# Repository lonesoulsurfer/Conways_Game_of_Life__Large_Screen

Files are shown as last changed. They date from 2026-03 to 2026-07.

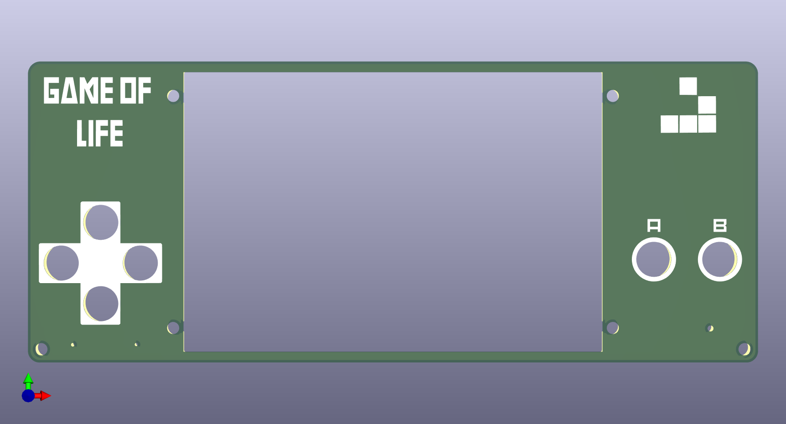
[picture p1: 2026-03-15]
Front Panel - Kicad 3D.png

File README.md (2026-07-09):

EKFB7789

**YouTube:** https://studio.youtube.com/video/bC17AgROvXw/edit

**Instructable:** https://www.instructables.com/Conways-Game-of-Life-XL-Screen-Raspberry-Pi-Projec/

### ▶ [Try the Web Simulator](https://htmlpreview.github.io/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) — no hardware required, runs in your browser

---

## Contents

- [Hardware & Setup](#hardware--setup)
- [Web Simulator](#web-simulator)
- [Main Menu](#main-menu)
- [Standard Controls](#standard-controls-conway--alt-games--rule-explorer)
- [Conway's Life Modes](#conways-life-modes)
- [Alternative Cellular Automata (Alt Games)](#alternative-cellular-automata-alt-games)
- [Lenia Sandbox](#lenia-sandbox)
- [Tools Menu](#tools-menu)
- [Arcade Games](#arcade-games)

---

## Hardware & Setup

The device runs on a Raspberry Pi Pico / RP2040 connected to a 3.5" ST7796S/ST7796U TFT display (480×320 pixels) via SPI. Six buttons handle all navigation and gameplay: Up, Down, Left, Right, SET (A), and B. A buzzer on GPIO 26 provides sound effects and music. Display brightness is PWM-controlled, and all settings (sound, volume, brightness) are saved to EEPROM so they persist between power cycles.

## Web Simulator

Don't have the hardware? [**Game_of_Life_Simulation.html**](Game_of_Life_Simulation.html) is a single-file, browser-based recreation of the firmware that runs on any modern desktop browser — [click here to launch it directly](https://htmlpreview.github.io/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), or download the file and open it locally.

It's a faithful port of the firmware's menu logic and simulation rules, built directly from this repo's source — not a from-scratch reimplementation. It covers:

- The full Conway's Life menu shell: Presets, Random, Symmetric, Custom, and Rule Explorer (including the Custom Rule bit editor)
- All seven Alt Games automata: Brian's Brain, Day & Night, Seeds, Cyclic CA, Wireworld, Langton's Ant, and Wolfram 1D
- The Lenia Sandbox, with its own live parameter panel and control scheme
- The Tools menu (Grid Lines, Population Counter, Trail Mode, Colour Mode, Toroidal World)

On-screen buttons mirror the physical Up/Down/Left/Right/A/B layout, and the same controls also work from a keyboard (arrow keys, A/Enter/Space, B) — including two-button combos like Up+Down for colour mode.

**Not included:** Arcade Games (Star Wars, Breakout Beyond, Gyruss) and hardware-only features like sound and screen brightness, which don't have a meaningful browser equivalent.

## Main Menu

On startup the device boots directly into the main scrolling menu with eight sections:

| # | Section | Description |
|---|---|---|
| 1 | Presets | Hand-crafted Conway's Life patterns |
| 2 | Random | Randomised Conway's Life |
| 3 | Symmetric | Procedurally generated symmetric patterns |
| 4 | Custom | Draw your own pattern |
| 5 | Rule Explorer | Define custom birth/survival rules |
| 6 | Alt Games | Alternative cellular automata (including Lenia Sandbox) |
| 7 | Tools | Display and simulation settings |
| 8 | Arcade | Three built-in arcade games |

Navigate with Up/Down, select with SET, go back with B.

## Standard Controls (Conway / Alt Games / Rule Explorer)

These controls apply to Conway's Life modes, Rule Explorer, and every Alt Games automaton except Lenia Sandbox, which has its own control scheme. See the [Lenia Sandbox](#lenia-sandbox) section.

| Button | Action |
|---|---|
| Up | Increase simulation speed |
| Down | Decrease simulation speed |
| Left | Cycle cell size (Small 3px, Normal 4px, Large 8px) |
| Right | Reset / regenerate the current pattern |
| Up + Down | Toggle colour mode |
| SET (hold) | Start simulation from edit mode |
| SET (hold, running) | Return to edit mode (Custom / Seeds / Brian's Brain only) |
| B (short press) | Return to menu |
| B (hold ~1 second) | Show/hide rules and information panel |

## Conway's Life Modes

### Presets (13 patterns)

Press SET once to open a preset, then A to start the simulation. While paused you can press Left to change cell size (the pattern rescales and redraws) or Right to reset it back to its starting state.

| # | Pattern | Notes |
|---|---|---|
| 1 | Coe Ship | Puffer-type spaceship that leaves debris trails |
| 2 | Gosper Gun | The first glider gun ever discovered, period 30 |
| 3 | Diamond | Symmetric expanding diamond pattern |
| 4 | Achim p144 | Rare period-144 oscillator |
| 5 | 56P6H1V0 | High-period spaceship |
| 6 | LWSS Convoy | Three Lightweight Spaceships in formation |
| 7 | MWSS | Middleweight Spaceship, 8 cells, speed c/2 |
| 8 | Pulsar | Period-3 oscillator with 4-fold symmetry, 48 cells |
| 9 | Pentadecathlon | 15-cell oscillator made from a modified 10-cell row |
| 10 | R-Pentomino | 5-cell seed that runs for 1,103 generations |
| 11 | Acorn | 7-cell methuselah running 5,206 generations |
| 12 | Simkin Gun | Smallest known glider gun, 36 cells, period 120 |
| 13 | Queen Bee | Period-30 oscillator, the first of its kind ever found |

### Random

Fills the board with random live cells at approximately 30% density. Immediately starts running. Press Right to re-randomise.

### Symmetric

Generates a random pattern with one of three symmetry types (vertical, horizontal, or rotational) in small, medium, or large sizes. Good for producing structured chaos.

### Custom

Puts the board into edit mode with a blinking red crosshair cursor. Move the cursor with Up/Down/Left/Right. Press SET to toggle a cell on or off. When happy with your pattern, hold SET for about a second to start the simulation. Hold SET again to return to edit mode. Press B to go back to the menu.

### Rule Explorer

Define your own cellular automaton by setting custom Birth (B) and Survival (S) rules, the same notation used by Life (B3/S23). Choose from 12 built-in rule presets or enter your own bit-by-bit. The simulation runs with your rules applied to a random starting board.

**Included preset rules:** High Life, 34 Life, Diamoeba, Replicator, Long Life, Maze, Coral, 2x2, Dry Life, Amoeba, Coagulate, Gnarl

## Alternative Cellular Automata (Alt Games)

**Brian's Brain.** A three-state automaton (On, Dying, Off) producing a constantly moving stream of light-speed "signals." Choose from small, medium, large, or random seedings, or draw a custom starting pattern.

**Day & Night** (B3678/S34678). A symmetric ruleset where dead and live regions are interchangeable. Dense regions survive and grow in a way that mirrors the original, creating organic, blob-like patterns.

**Seeds** (B2/S). Every live cell dies every generation but any dead cell with exactly two live neighbours is born. Creates explosive, constantly moving patterns that never stabilise.

**Cyclic CA.** A multi-state automaton where cells cycle through states 0→1→2→…→N→0. Cells advance only when they have a neighbour in the next state. Produces rotating spiral waves. Choose small, medium, or large seedings.

**Wireworld.** A four-state automaton (Empty, Wire, Electron Head, Electron Tail) that models digital logic circuits. Electrons travel along wires, interact at junctions, and can form AND gates and clocks. The built-in demo includes a working circuit layout.

**Langton's Ant.** A single ant on a grid follows two rules: turn right on a white cell and flip it black, turn left on a black cell and flip it white. After roughly 10,000 chaotic steps it spontaneously builds a repeating diagonal "highway." Toggle age-colour mode with Up+Down to see a heat map of how often each cell has been visited.

**Wolfram 1D Automata.** One-dimensional elementary cellular automata: a single row of cells evolves downward according to one of 255 possible rules. Each rule produces a unique pattern, from pure chaos (Rule 30) to the Sierpinski triangle (Rule 90) to a Turing-complete system (Rule 110). Seven named presets are provided, or you can enter any rule number directly.

**Lenia Sandbox.** A continuous cellular automaton with its own control scheme, described below.

## Lenia Sandbox

Unlike every automaton above, Lenia isn't discrete. Cells hold a value from 0-255 instead of a simple on/off state, and each step blends that value with a weighted neighbourhood (the kernel) instead of applying binary birth/survival rules. The result is smooth, organic life forms that grow and drift.

The play area occupies the right two-thirds of the screen, with a live parameter panel on the left third.

**Parameters** (adjust with Up/Down to select, Left/Right to change value):

| Parameter | Meaning |
|---|---|
| Mu | Growth centre: the neighbourhood value that produces the strongest growth |
| Sigma | Growth width: how forgiving that target value is |
| Radius | How far each cell looks at its neighbours |
| Speed | How much each step nudges the field (time step / dt) |

**Controls:**

| Button | Action |
|---|---|
| Up / Down | Select a parameter row |
| Left / Right | Adjust the selected parameter |
| SET (A) | Reseed the board with fresh random blobs |
| Up + Down | Toggle colour scheme (blue/cyan/white or fire) |
| B (short tap) | Return to the Alt Games menu |
| B (hold ~1 second) | Show/hide the rules and parameter info panel |
| SET + B (hold ~1 second) | Full reset: parameters back to defaults, fresh seed |

Honours the shared Toroidal World setting from the Tools menu (wrap edges on/off) and the Auto-Cycle screensaver tool (periodically reseeds on its own, same as the other automata).

## Tools Menu

**Grid Lines.** Overlays a faint grid matching the current cell size.

**Population Counter.** Shows live cell count and generation number during simulation.

**Trail Mode.** Dying cells leave a soft 20-step fade trail rather than disappearing instantly.

**Colour Mode.** Age-based colouring; young cells are one colour, older cells shift through the spectrum.

**Toroidal World.** When on, edges wrap around so the board is a torus. When off, edges are hard boundaries.

**Brightness.** Four levels: 25%, 50%, 75%, 100%.

**Auto-Cycle / Screensaver.** Automatically switches to a random game mode or Wolfram rule every 300 generations. Useful as a display piece.

**Sound settings.** Enabled/disabled, three volume levels. Also accessible here and saved to EEPROM.

## Arcade Games

Accessed from main menu item 8. Three games are available. In all three, press A + B together at any time to exit directly back to the main menu.

### Star Wars

A first-person Star Wars game inspired by the 80's arcade game. Progress through multiple stages: Womp Rat Training, Space Battle, Death Star Approach, Surface Run, and the Exhaust Port shot. Features full Star Wars music (Main Theme, Binary Sunset, Imperial March, Victory Fanfare), sound effects, TIE fighters, laser cannons, proton torpedoes, and a dramatic finale sequence. Press B on the title screen to exit.

| Button | Action |
|---|---|
| Up/Down/Left/Right | Move crosshair / pilot ship |
| SET | Fire |
| A + B | Exit to main menu |
| Up + Down (title screen) | Enter games menu to play any of the games or watch the cinematic shorts |

### Breakout Beyond

A feature-rich Breakout variant with a neon aesthetic. The paddle sits at the bottom, bricks at the top. Features include combo multipliers, spin physics, multiball, shield power-ups, bomb bricks, and hard bricks across 20 levels.

| Button | Action |
|---|---|
| Left/Right | Move paddle |
| B | Speed boost |
| SET | Launch ball / pause |
| A + B (hold) | Exit to main menu |

### Gyruss

A circular shoot-em-up inspired by the 1983 Konami arcade classic. Your ship orbits around the edge of the screen shooting inward at waves of enemies that fly in formation patterns.

| Button | Action |
|---|---|
| Left/Right | Rotate ship around the ring |
| SET or B | Fire |
| Up (hold) | Smart bomb |
| A + B (hold) | Exit to main menu |

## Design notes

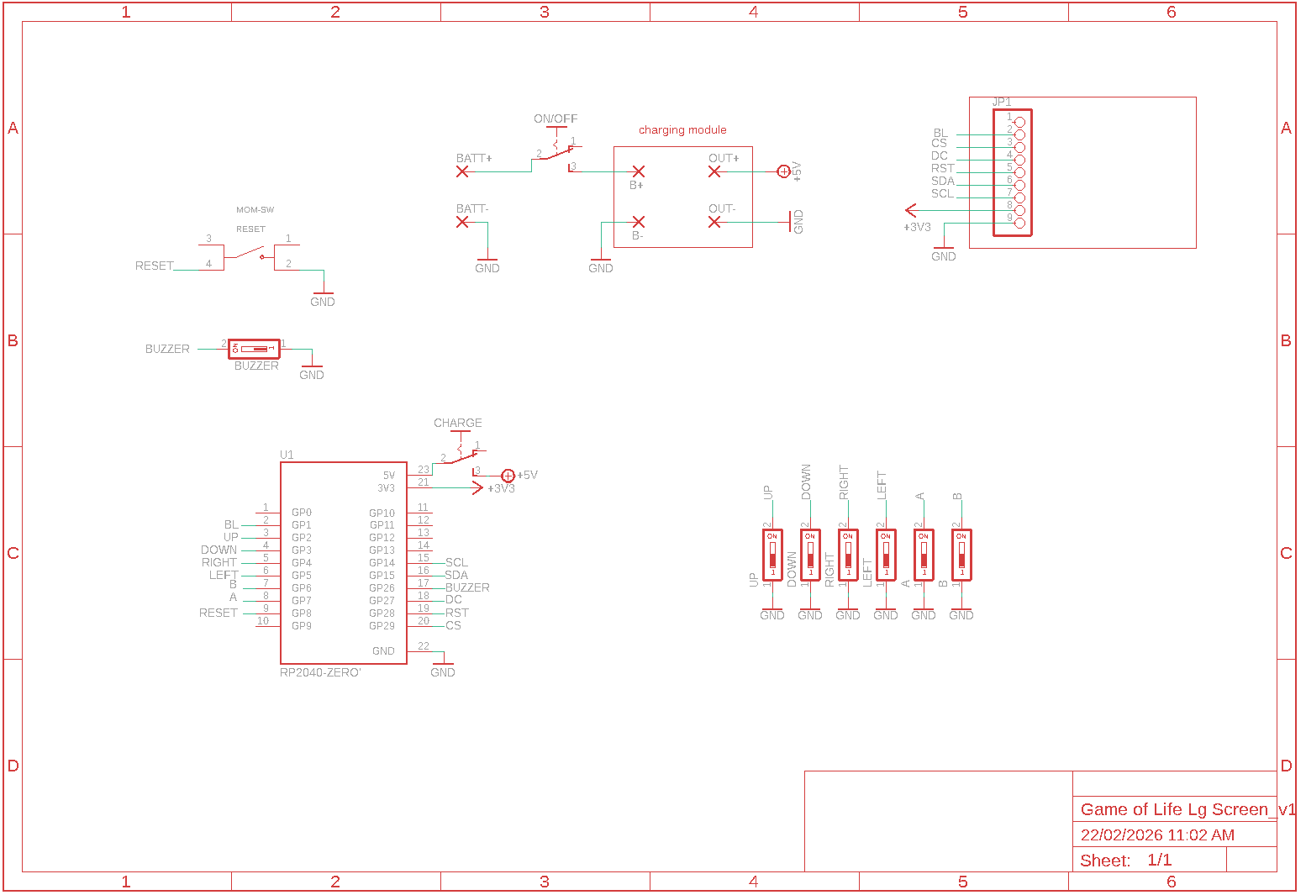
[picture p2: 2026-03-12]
Schematic.png

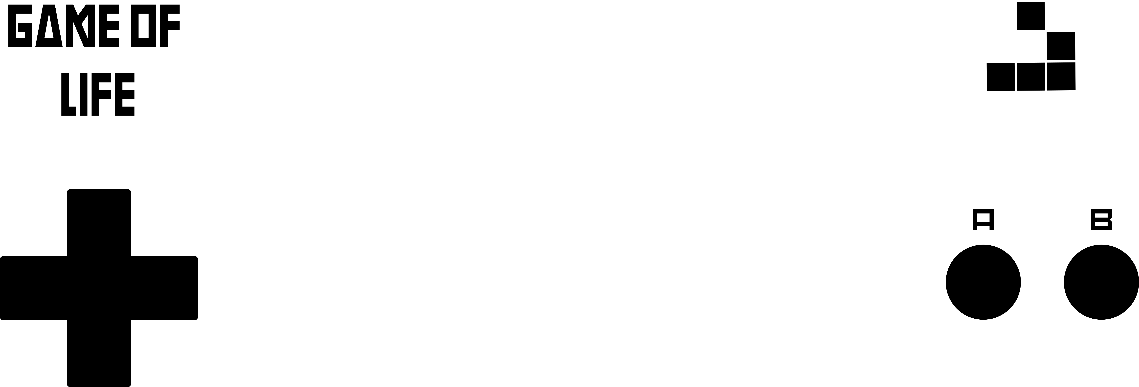
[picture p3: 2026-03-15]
Panel Design/Front Panel/GOL - Lg Sceen - Front Panel.png

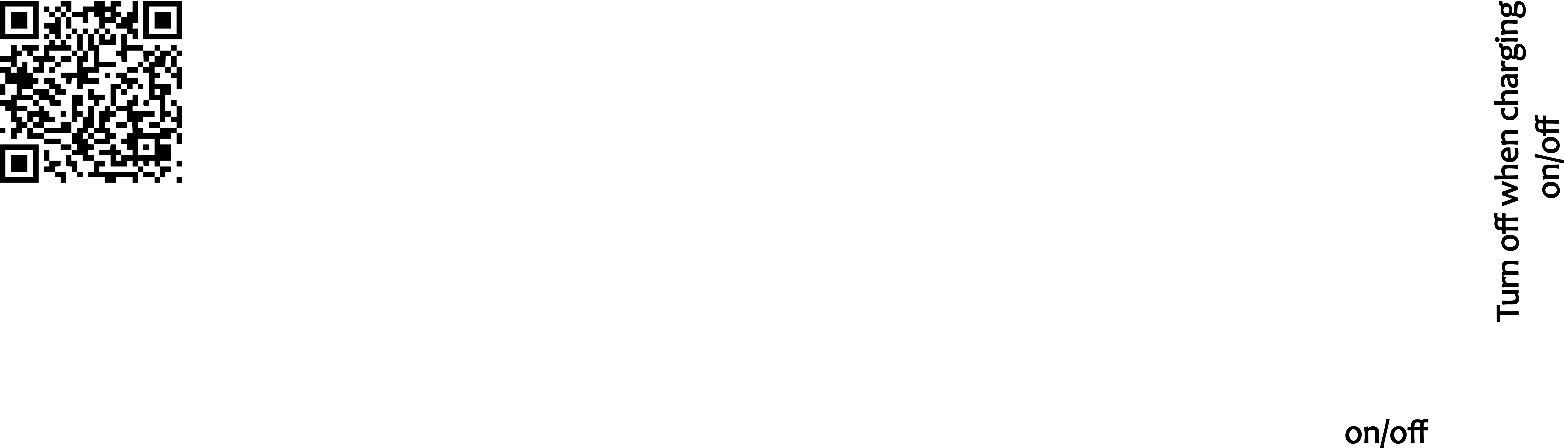
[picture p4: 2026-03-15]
Panel Design/Back Panel/Game of Life Lg Screen - Back Panel.png

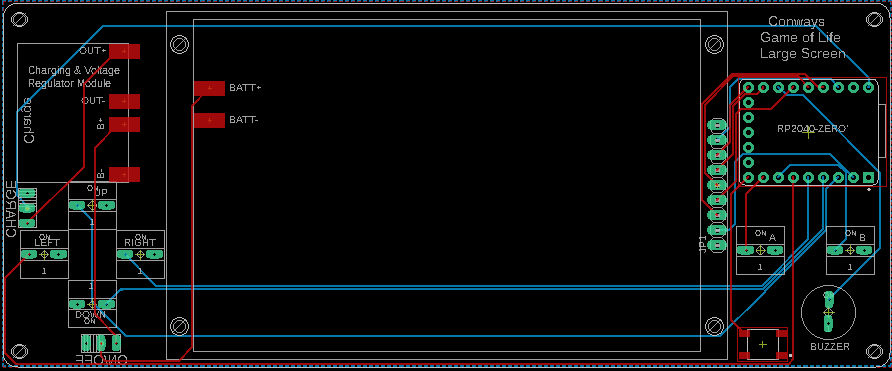
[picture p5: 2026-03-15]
Board.png

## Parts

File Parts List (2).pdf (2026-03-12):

Part | Type | Part Number | Qty | Link | Image
Switches | Momentary Switches Slide Switch Tactile Tact Push Button -4 pin | SKRCADD010 MSK-12D19 | 6 2 1 | Link (https://www.aliexpress.com/item/4000550502648.html) Link (https://www.aliexpress.com/item/32828124825.html?srcSns=sns_More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) Link (https://www.aliexpress.com/item/1005006195658674.html?curPageLogUid=UlWXQG9WxOqp)

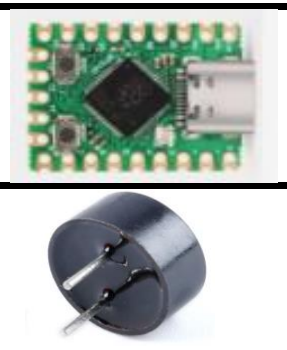
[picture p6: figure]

Raspberry Pi Pico Zero | | | 1 | Link (https://www.aliexpress.com/w/wholesale-Raspberry-PI-Pico-Mini-RP2040%2525252dZERO-Microcontroller.html)
Buzzer | Passive (9mm X 3.2mm) SMD | | 1 | Link (https://www.aliexpress.com/w/wholesale-9042-buzzer.html?spm=a2g0o.detail.search.0)
TFT Display | 3.5 inch OLED LCD Drive IC 320 X 480 | ST7796S/ ST7796U | 1 | Link (https://www.aliexpress.com/w/wholesale-TFT-Display-2.0-inch-OLED-LCD-Drive-IC-ST7789V-240.html)

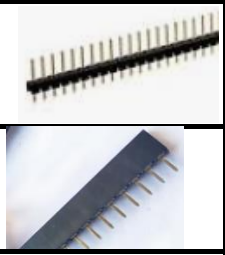
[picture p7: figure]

Header Pins | Male - SMT 2.54mm | | (2 X 9) | Link (https://www.aliexpress.com/w/wholesale-pin-headers-single-row.html?spm=a2g0o.productlist.search.0)
| Female - Lo profile | | (2 X 9) | Link (https://www.aliexpress.com/item/1005004122312694.html?curPageLogUid=kHqHT0cRd9pW)
Nylon Hex Spacers | M2 - assorted | | 1 | Link (https://www.aliexpress.com/item/1005007123661699.html)
Hex Socket Screw Kit | Ms - Assorted | DIN912 | 1 | Link (https://www.aliexpress.com/item/1005007273134914.html?curPageLogUid=XMboOUAJHQU8)
Battery | Lipo - (Mobile) | EB-BJ700BBC EB-BJ700CBE | 1 | Link (https://www.aliexpress.com/item/1005007768846321.html?curPageLogUid=MjolbnGyNA4R)
Charging & Voltage Module | 3.7V To 9V 5V 2A DC-DC Step Up Boost Modul | | 1 | Link (https://www.aliexpress.com/item/1005005656423941.html?srcSns=sns_More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)

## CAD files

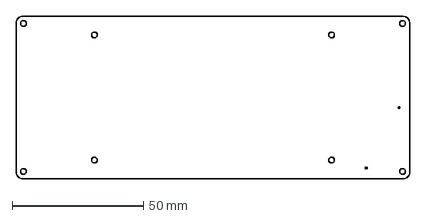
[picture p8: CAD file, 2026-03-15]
Panel Design/Back Panel/GOL Lg Screen - Back Panel - Fusion.dxf
150.1 x 61.9 mm

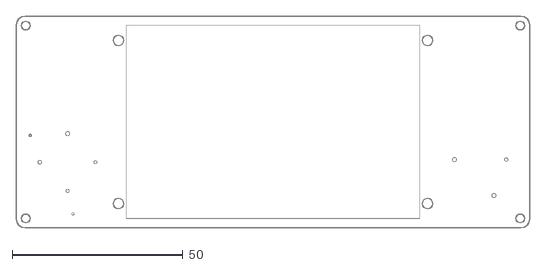
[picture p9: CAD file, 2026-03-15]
Panel Design/Front Panel/Game of Life Lg Screen PCB.dxf
150.1 x 61.9

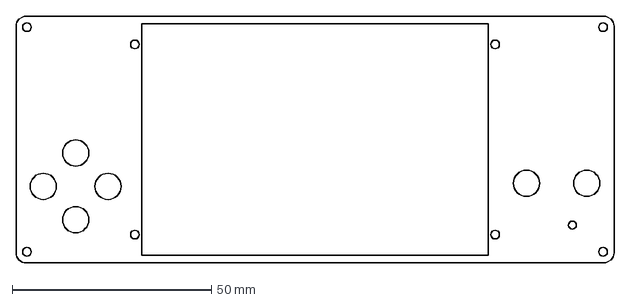
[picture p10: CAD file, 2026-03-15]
Panel Design/Front Panel/Game of Life Lg Screen Fusion.dxf
150.1 x 61.9 mm

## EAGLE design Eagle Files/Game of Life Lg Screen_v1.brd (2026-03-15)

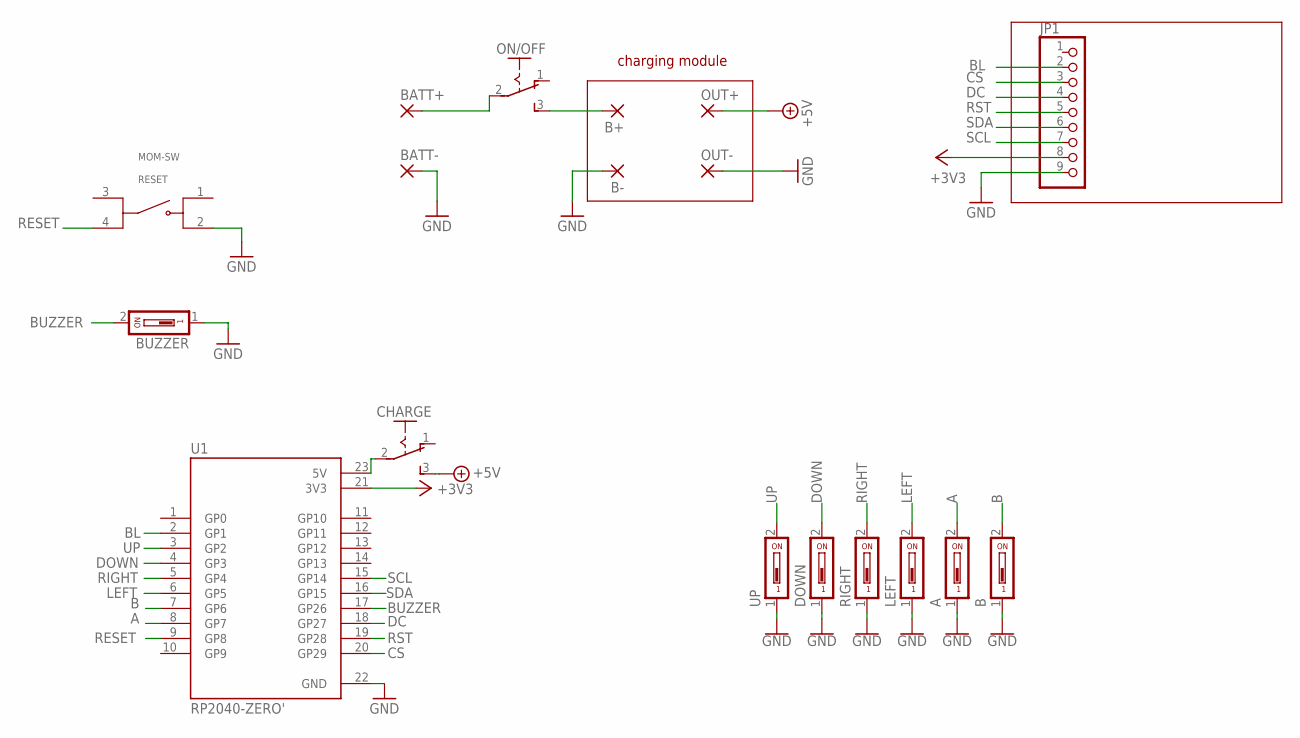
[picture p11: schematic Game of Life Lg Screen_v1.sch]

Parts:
A: DS01; DS-01
B: DS01; DS-01
B+: SMD5; SMD2,54-5,08
B-: SMD5; SMD2,54-5,08
BATT+: SMD5; SMD2,54-5,08
BATT-: SMD5; SMD2,54-5,08
BUZZER: DS01; DS-01
CHARGE: M251
DOWN: DS01; DS-01
JP1: PINHD-1X9; 1X09
LEFT: DS01; DS-01
ON/OFF: M251
OUT+: SMD5; SMD2,54-5,08
OUT-: SMD5; SMD2,54-5,08
RESET: MOM-SW; SW_TS18-5-25-SL-260-SMT-TR
RIGHT: DS01; DS-01
U1: RP2040-ZERO'; MODULE_RP2040-ZERO
UP: DS01; DS-01

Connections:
+3V3: JP1.8, U1.21 (3V3)
+5V: CHARGE.3 (S), OUT+.1
A: A.2, U1.8 (GP7)
B: B.2, U1.7 (GP6)
BL: JP1.2, U1.2 (GP1)
BUZZER: BUZZER.2, U1.17 (GP26)
CS: JP1.3, U1.20 (GP29)
DC: JP1.4, U1.18 (GP27)
DOWN: DOWN.2, U1.4 (GP3)
GND: A.1, B.1, B-.1, BATT-.1, BUZZER.1, DOWN.1, JP1.9, LEFT.1, OUT-.1, RESET.2, RIGHT.1, U1.22 (GND), UP.1
LEFT: LEFT.2, U1.6 (GP5)
unnamed: B+.1, ON/OFF.3 (S)
unnamed: CHARGE.2, U1.23 (5V)
unnamed: BATT+.1, ON/OFF.2
RESET: RESET.4, U1.9 (GP8)
RIGHT: RIGHT.2, U1.5 (GP4)
RST: JP1.5, U1.19 (GP28)
SCL: JP1.7, U1.15 (GP14)
SDA: JP1.6, U1.16 (GP15)
UP: U1.3 (GP2), UP.2

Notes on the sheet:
charging module

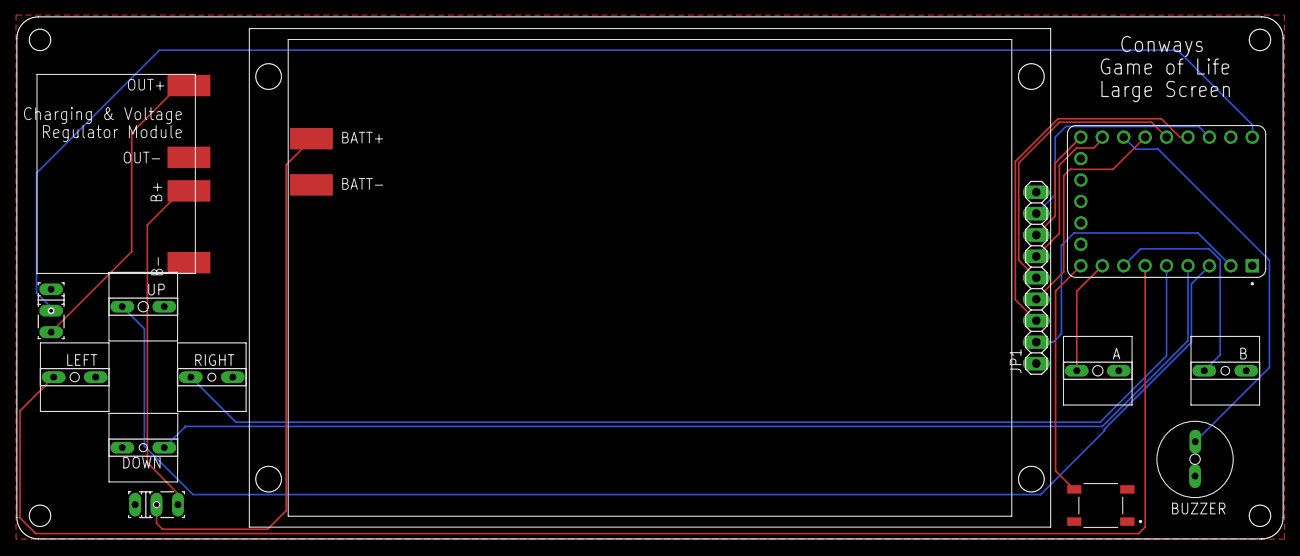
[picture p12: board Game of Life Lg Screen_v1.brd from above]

Board: 2 copper layers, 150.1 x 61.9 mm, 18 parts (0 on the bottom side), 20 nets.

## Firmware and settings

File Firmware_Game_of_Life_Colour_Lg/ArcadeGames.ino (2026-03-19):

/*
 * =====================================================================
 *   ArcadeGames.ino — Breakout + Gyruss for Game_of_Life_Colour
 *   Ported from RetroArcade (320×240 Adafruit_ST7789)
 *   Target: ST7796S 480×320, Arduino_GFX_Library
 *
 *   Place in the same sketch folder as Game_of_Life_Colour.ino
 *   and StarWars.ino.
 *
 *   Entry points (called from Game_of_Life_Colour.ino):
 *     void runBreakout()    — runs until player quits, then returns
 *     bool gyrussLoop()     — call in a loop; returns true when player exits
 * =====================================================================
 *
 *  BREAKOUT BEYOND CONTROLS
 *    LEFT / RIGHT → move paddle         B → speed boost
 *    
 *    FIRE (SET)  → launch ball / pause
 *    SET + B      → exit to arcade menu
 *
 *  GYRUSS CONTROLS
 *    LEFT / RIGHT  → rotate ship around ring
 *    SET or B      → fire (not both — both = exit combo)
 *    SET + B held  → exit to arcade menu
 *    UP (hold)     → smart bomb
 * =====================================================================
 */

// ── File ordering note ────────────────────────────────────────────────────
// Arduino IDE merges .ino files alphabetically before compiling.
// "ArcadeGames" sorts before "Game_of_Life_Colour", so Arduino_GFX types
// and isBtnXxx() helpers aren't yet visible here.  We work around this by:
//   1. Including the Arduino_GFX header directly (harmless duplicate include).
//   2. Forward-declaring every cross-file symbol we need.
//   3. Forward-declaring Gyruss functions called before their definition.

#include <Arduino_GFX_Library.h>

// display and playTone() are declared in Game_of_Life_Colour.ino
extern Arduino_GFX *display;
extern void playTone(int frequency, int duration);
extern bool soundEnabled;
extern bool arcadeExitToMain;  // set true when A+B pressed to go to main menu

// Button helpers (defined in Game_of_Life_Colour.ino)
extern bool isBtnUp();
extern bool isBtnDown();
extern bool isBtnLeft();
extern bool isBtnRight();
extern bool isBtnSet();
extern bool isBtnB();

// ── Redirect RetroArcade's blocking beepTone to GoL's playTone ─────────────
// playTone already guards soundEnabled, so no extra check needed here.
static inline void beepTone(int freq, int durationMs) {
  playTone(freq, durationMs);
}

// ── Shared sound helpers (only menu-navigation sounds shared here) ──────────
// Game-specific sounds are defined in each game's section below.
static void sndMenuMove()  { beepTone(800,  25); }
static void sndSelect()    { beepTone(600,  35); beepTone(900, 55); }

// ── Colour palette (RGB565) — prefixed ARC_ to avoid collision with GoL ────
#define ARC_BLACK    0x0000
#define ARC_WHITE    0xFFFF
#define ARC_RED      0xF800
#define ARC_GREEN    0x07E0
#define ARC_BLUE     0x001F
#define ARC_CYAN     0x07FF
#define ARC_MAGENTA  0xF81F
#define ARC_YELLOW   0xFFE0
#define ARC_ORANGE   0xFD20
#define ARC_DKGRAY   0x39E7
#define ARC_LTGRAY   0xCE79
#define ARC_DKBLUE   0x000F
#define ARC_TEAL     0x03EF
#define ARC_GOLD     0xFEA0


// ══════════════════════════════════════════════════════════════════════════
//
//                   B R E A K O U T   B E Y O N D
//
//  Inspired by Atari / Choice Provisions Breakout Beyond (2025).
//  Paddle on the LEFT, bricks on the RIGHT.
//  Goal: get the ball past the right edge to advance — don't clear every brick.
//  Combo multiplier, spin physics, multiball, shield, bomb powerups.
//  Neon aesthetic: glowing ball trail, bright colours, dark background.

// ══════════════════════════════════════════════════════════════════════════
//
//                   B R E A K O U T   B E Y O N D
//
//  Classic Breakout orientation (paddle at bottom, bricks at top) with
//  Breakout Beyond-inspired features: combo multiplier, spin physics,
//  multiball, shield, bomb bricks, hard bricks, neon aesthetic.
//
//  CONTROLS
//    LEFT / RIGHT → move paddle         B → speed boost
//    FIRE (SET)   → launch ball / pause
//    SET + B      → exit to arcade menu
//
// ══════════════════════════════════════════════════════════════════════════

// ── Layout (480×320 landscape) ────────────────────────────────────────────
#define BRK_STATUS_H      20          // top status bar

// Play field
#define BRK_PLAY_TOP      (BRK_STATUS_H + 1)
#define BRK_PLAY_BOTTOM   318
#define BRK_PLAY_LEFT     1
#define BRK_PLAY_RIGHT    478

// Paddle at bottom, moves left/right
#define BRK_PADDLE_Y      304
#define BRK_PADDLE_H      11
#define BRK_PADDLE_W_BASE 70

// Ball
#define BRK_BALL_R        6

// Bricks — 12 columns × 7 rows filling the upper portion
#define BRK_COLS          12
#define BRK_ROWS           7
#define BRK_W             36          // (480 - 2*margin) / 12 - gap ≈ 36
#define BRK_H             20
#define BRK_GAP_X          3
#define BRK_GAP_Y          3
// Centre the grid: 12*(36+3)=468, margin=(480-468)/2=6
#define BRK_X0             6
#define BRK_Y0            (BRK_PLAY_TOP + 4)

// ── EEPROM ────────────────────────────────────────────────────────────────
#define EEPROM_BRK_HI 4

// ── Neon colour themes — 4 palettes cycling every 5 levels ───────────────
static const uint16_t BRK_THEMES[4][7] = {
  // Theme 0 — Classic Neon (levels 1-5)
  { 0xF81F, 0xF800, 0xFD20, 0xFFE0, 0x07E0, 0x07FF, 0x001F },
  // Theme 1 — Solar Flare (levels 6-10)
  { 0xFFE0, 0xFD20, 0xFB00, 0xF800, 0xF81F, 0xC81F, 0x801F },
  // Theme 2 — Ice Storm (levels 11-15)
  { 0xFFFF, 0xAFFF, 0x07FF, 0x055F, 0x001F, 0x601F, 0xF81F },
  // Theme 3 — Toxic (levels 16-20)
  { 0x07E0, 0x4FE0, 0xAFE0, 0xFFE0, 0xFD20, 0xF800, 0x07FF },
};
static const int BRICK_PTS[7] = { 120, 100, 90, 80, 70, 60, 50 };
// Mutable active palette — set at the start of each level
static uint16_t BRICK_COL[7];

// ── Brick types ───────────────────────────────────────────────────────────
#define BTYPE_EMPTY   0
#define BTYPE_NORMAL  1
#define BTYPE_HARD    2   // 2 hits; drawn with double border
#define BTYPE_BOMB    3   // clears 3×3 region on break
#define BTYPE_MULTI   4   // spawns a second ball on break
#define BTYPE_SHIELD  5   // grants a bottom safety net for a few seconds
#define BTYPE_TURBO   6   // speeds ball up for 10 seconds
#define BTYPE_SHRINK  7   // shrinks paddle by a third for 8 seconds

// ── Game state ────────────────────────────────────────────────────────────
static uint8_t brk_bricks[BRK_ROWS][BRK_COLS];
static int     brk_bricksLeft;

#define BRK_MAX_BALLS 3
struct BrkBall {
  float x, y, vx, vy;
  bool  active;
  float trailX[8], trailY[8];
  int   trailHead;
};
static BrkBall brk_balls[BRK_MAX_BALLS];

static float brk_px;          // paddle left edge
static int   brk_pw;          // paddle width
static bool  brk_launched;
static int   brk_lives;
static int   brk_score;
static int   brk_hiScore;
static int   brk_level;
static int   brk_combo;       // consecutive brick hits
static int   brk_mult;        // score multiplier 1–8
static bool  brk_speedBoost;  // B toggles fast paddle speed
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

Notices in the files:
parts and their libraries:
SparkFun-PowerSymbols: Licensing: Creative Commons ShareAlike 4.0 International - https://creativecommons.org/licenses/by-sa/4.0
